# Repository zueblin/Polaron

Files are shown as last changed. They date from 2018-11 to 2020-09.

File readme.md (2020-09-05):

# Polaron

Polaron is a DIY digital drum machine based on the [Teensy 3.6](https://www.pjrc.com/teensy/) USB Microcontroller plattform.

Main features:

- 16 step sequencer
- 6 instrument tracks
- 16 patterns per track
- load/save projects to SD card
- 2 pots for parameter control
- parameter locks: all instrument parameters can be recorded for each step
- different pattern length for each instrument track
- sync to midi-clock (usb-midi) or trigger input
- crunchy 12bit stereo outputs
- open source hardware/software: if you miss a feature or are annoyed by a bug... change it!

Disclaimer: This is a DIY project, features may change or not work for you. Use at your own risk.

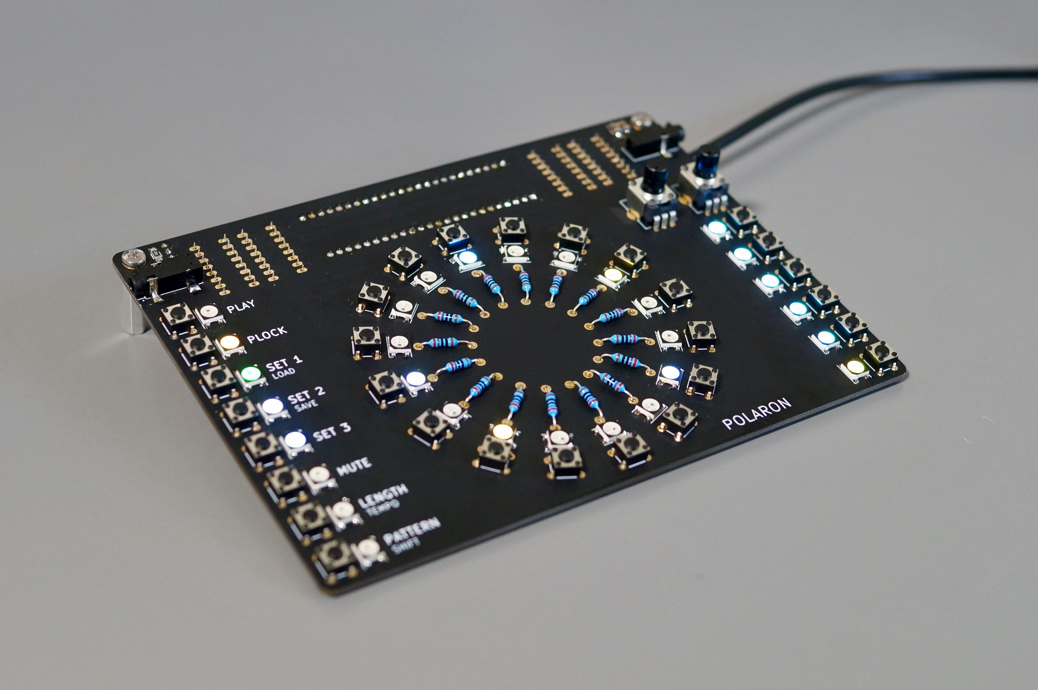
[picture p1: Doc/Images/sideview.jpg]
Sideview


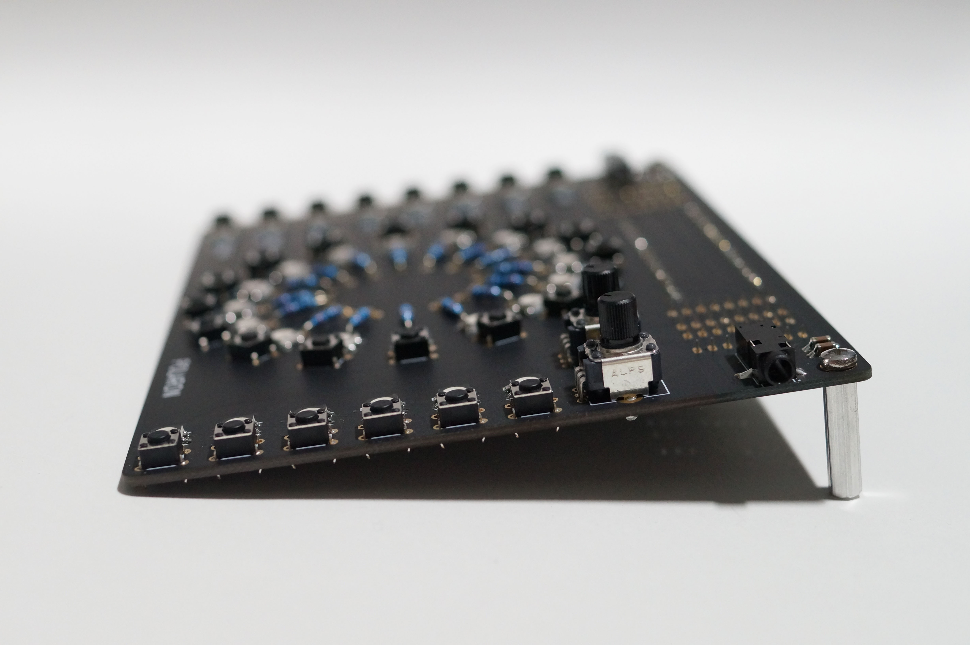
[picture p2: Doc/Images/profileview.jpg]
Profile


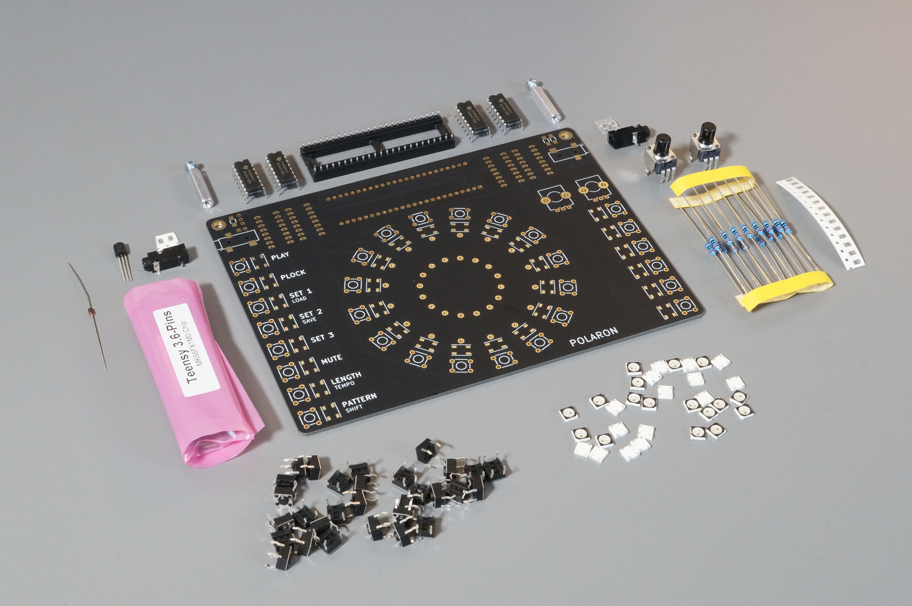
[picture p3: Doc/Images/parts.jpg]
Parts


here's some short videos:

https://www.youtube.com/watch?v=JC_pZTxMb0c

https://vimeo.com/302283771

https://vimeo.com/305113707

Follow the project on Instagram: https://www.instagram.com/polaron.me/

And don't forget to check the [Project WIKI](https://github.com/zueblin/Polaron/wiki) for more info.

## Software

To build the software, the following tools are required:

- [Arduino IDE](https://www.arduino.cc/en/Main/Software) (tested with 1.8.6)
- [Teensyduino Add-On](https://www.pjrc.com/teensy/teensyduino.html) (tested with 1.43)

## Hardware

PCB is designed using KICAD 5.1.2

Parts needed (Rev 1.4):

- Teensy 3.6 32bit Microcontroller (with Headers)
- 30 x WS2812b RGB LEDs (or SK6812)
- 30 x 6x6mm Pushbuttons (ideally 4.3mm height, 100gf) (Mouser: 688-SKHHAJ)
- 16 x 270 ohm throughhole Resistors (Mouser: 603-MF0207FTE52-270R)
- 14 x 270 ohm SMD Resistors (1206 housing)
- 2 x 10k SMD Resistors (1206 housing)
- 1 x 1N4148 diode
- 1 x 2N3904BU transistor
- 4 x SN74HC165N Shiftregister (Mouser: 595-SN74HC165N)
- 2 x ALPS Potentiometer (RK09K1130A8G)
- 2 x 2.2 uF SMD Capacitor (1206 housing, Mouser: 963-TMK316BJ225KL-T)
- 2 x Audio Jack (SJ-352X-SMT)
- 1 x 48 Position / 2 Row IC DIP Socket (Mouser: 517-4848-6004-CP)
- 2 x 20mm PCB Standoff with 3mm thread (Mouser: 534-24437)

Check the Wiki for [Build Instructions](https://github.com/zueblin/Polaron/wiki/Building-the-Polaron)

## Known Issues:
PCB Rev 1.4

- In some situations, when connecting the polaron to a computer via usb and connecting the polaron audio output to an audio interface that is connected to the computer (e.g via thunderbolt), a ground loop is created. This results in a very noticable noise/whine in the audio channel (which is caused by the LED PWM). Tested solution: [Audio Ground Loop Noise Isolator](https://www.pjrc.com/store/audio_ground_isolator.html)

## FAQ

- Q: Is this an easy build? A: This is an intermediate project to build. Its not very complicated, but there are some SMD parts which are not easy to get right (the LEDs). You'll need a decent soldering iron, with a rather fine tip.
- Q: Is this a pro audio project? A: No, not exactly. The Polaron is more about a fun workflow than super hifi sound.
- Q: Does it work with a Teensy 3.5? A: PJRC forum member drjohn reports successfully running the Polaron with a Teensy 3.5.
- Q: Does it work with a Teensy 4.0 / 4.1? A: No, the Polaron relies on the internal DAC of the Teensy 3.6 and is not compatible with Teensy 4.0 / 4.1
- Q: Is there a manual? A: Yes, please check the [Project WIKI](https://github.com/zueblin/Polaron/wiki) for build instructions and operating manual. If you still have questions / suggestions, please send me a mail.
- Q: Does the polaron fit into a euro-rack? A: No, not really (PCB size is 15.7cm x 11.6cm). Polaron builder N.Shaver has experimented with a 3D printable eurorack case for the polaron which he shares on [Thingiverse](https://www.thingiverse.com/thing:3830556)
- Q: Can i buy a PCB? A: Sold out, but let me know if you'd be interested in buying one. ~~Yes, i currently have PCBs at 15 USD (+ shipping from switzerland). Please contact me by email, if interested.~~
- Q: Can i buy a part-kit? A: I don't sell part kits anymore, since it is very easy and efficient to order parts online, eg. from mouser. ~~Yes, i currently have part kits (PCB + all parts, EXCLUDING the teensy itself) at 60 USD incl. untracked international shipping. Add 5 USD for tracked shipping. Please send me a mail, if interested.~~
- Q: Can i buy a fully assembled Polaron? A: Not, not at the moment.
- Q: How can i support this project? A: Spread the word, star the project on github, let your friends know, buy a PCB, build a Polaron and share a video...there are many ways. In general, knowing that this project sparks some interest is what keeps it going!

# License

Code: MIT

Hardware: cc-by-sa-3.0

By: Thomas Zueblin (thomas.zueblin@gmail.com)

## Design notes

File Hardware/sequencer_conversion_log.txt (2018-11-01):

#********** START OF renumber-sheet.ulp ULP Version 4.4.4 10-11-2017 :09:17:23 LOG **********#
    Conversion completed with no Messages
#********** END OF renumber-sheet.ulp ULP Version 4.4.4 10-11-2017 :09:17:23 LOG **********#

#********** START OF fix_via_hack.ulp ULP Version 4.8.0 10-11-2017 :09:17:44 LOG **********#
VIA	ViaCount=1		Net=N$9				(X=8890.000000 Y=25400.000000)	LayerStart=1	LayerEnd=16
VIA	ViaCount=2		Net=N$10				(X=21590.000000 Y=30480.000000)	LayerStart=1	LayerEnd=16
VIA	ViaCount=3		Net=N$11				(X=17780.000000 Y=35560.000000)	LayerStart=1	LayerEnd=16
VIA	ViaCount=4		Net=N$12				(X=64770.000000 Y=31750.000000)	LayerStart=1	LayerEnd=16
VIA	ViaCount=5		Net=N$13				(X=39370.000000 Y=31750.000000)	LayerStart=1	LayerEnd=16
VIA	ViaCount=6		Net=N$14				(X=41910.000000 Y=17780.000000)	LayerStart=1	LayerEnd=16
VIA	ViaCount=7		Net=N$15				(X=62230.000000 Y=17780.000000)	LayerStart=1	LayerEnd=16
VIA	ViaCount=8		Net=N$16				(X=21590.000000 Y=17780.000000)	LayerStart=1	LayerEnd=16
VIA	ViaCount=9		Net=N$17				(X=71120.000000 Y=24130.000000)	LayerStart=1	LayerEnd=16
PADFILL	PadCount=19		Net=GND				(X=6680.000000 Y=15912.000000)	LayerStart=1	LayerEnd=1
PADFILL	PadCount=23		Net=GND				(X=16840.000000 Y=15912.000000)	LayerStart=1	LayerEnd=1
PADFILL	PadCount=27		Net=GND				(X=27000.000000 Y=15912.000000)	LayerStart=1	LayerEnd=1
PADFILL	PadCount=31		Net=GND				(X=37160.000000 Y=15912.000000)	LayerStart=1	LayerEnd=1
PADFILL	PadCount=35		Net=GND				(X=47320.000000 Y=15912.000000)	LayerStart=1	LayerEnd=1
PADFILL	PadCount=39		Net=GND				(X=57480.000000 Y=15912.000000)	LayerStart=1	LayerEnd=1
PADFILL	PadCount=43		Net=GND				(X=67640.000000 Y=15912.000000)	LayerStart=1	LayerEnd=1
PADFILL	PadCount=47		Net=GND				(X=77800.000000 Y=15912.000000)	LayerStart=1	LayerEnd=1
#********** END OF fix_via_hack.ulp ULP Version 4.8.0 10-11-2017 :09:17:44 LOG **********#

#********** START OF eagle6xx-sch-to-kicad-sch.ulp 2.0 10-11-2017 :09:18:30 LOG **********#
    Conversion completed with no Messages
#********** END OF eagle6xx-sch-to-kicad-sch.ulp 2.0 10-11-2017 :09:18:30 LOG **********#

#********** START OF exp-lbrs.ulp 6.8 10-11-2017 :09:19:15 LOG **********#
OK: Eagle library export from SCH/PCB successful
    Conversion completed with no messages
#********** END OF exp-lbrs.ulp 6.8 10-11-2017 :09:19:15 LOG **********#

#********** START OF eagle-lbr2kicad-1.0.ulp 3.1 10-11-2017 :09:19:25 LOG **********#
    Conversion completed with no Messages
#********** END OF eagle-lbr2kicad-1.0.ulp 3.1 10-11-2017 :09:19:25 LOG **********#

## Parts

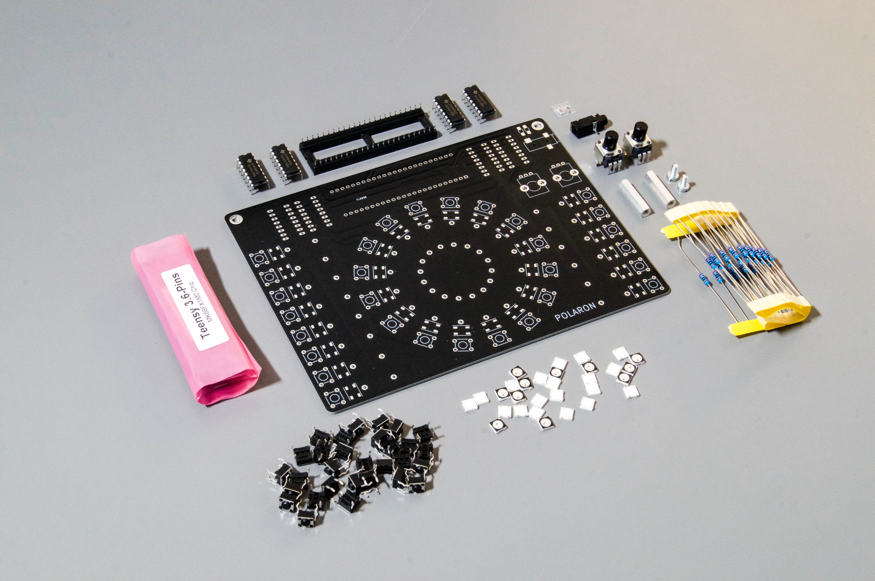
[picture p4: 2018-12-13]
Doc/Images/assembly/parts.jpg

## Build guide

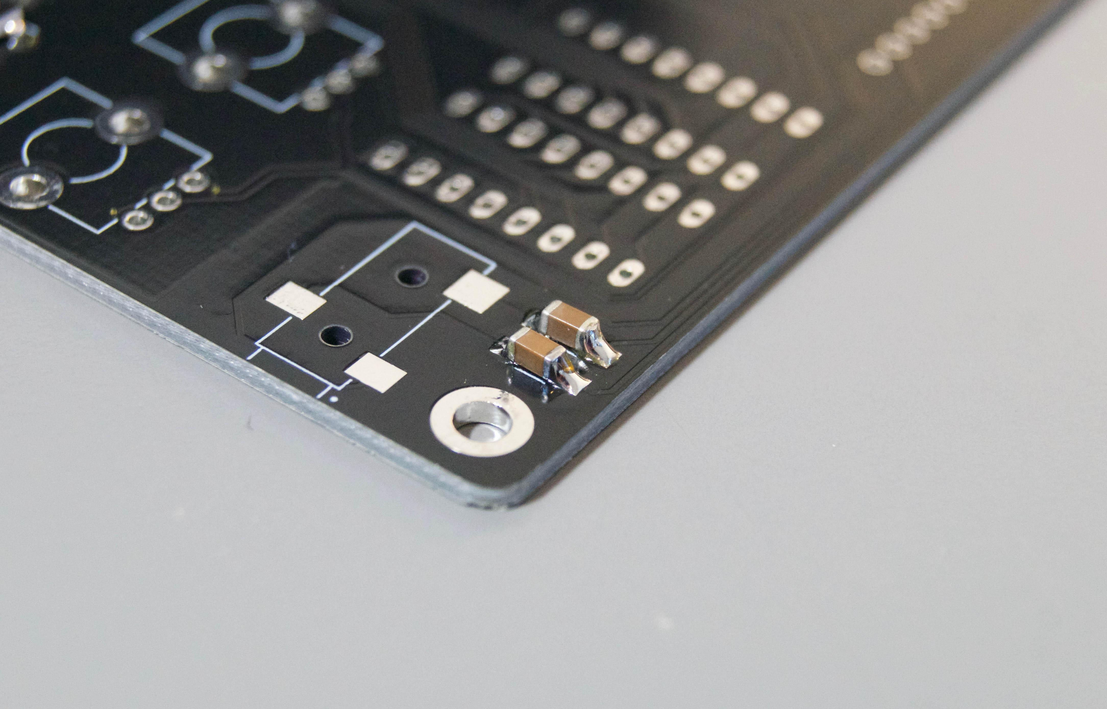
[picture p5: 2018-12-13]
Doc/Images/assembly/smd-cap.jpg

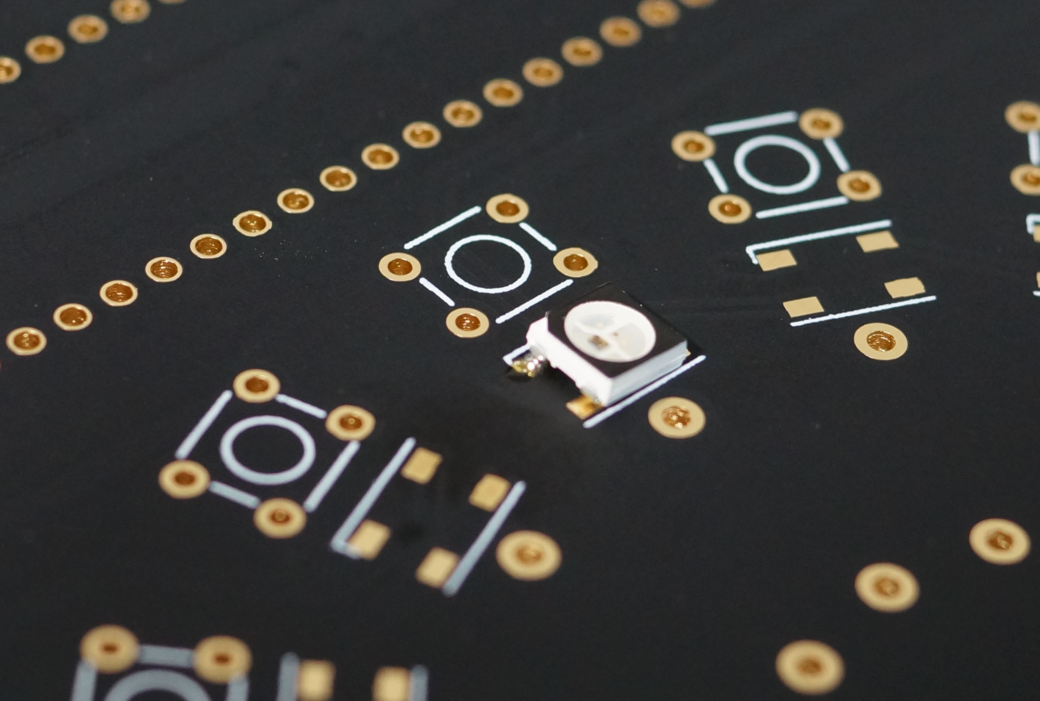
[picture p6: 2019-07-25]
Doc/Images/assembly/rev-1.4/led-dot-1.jpg

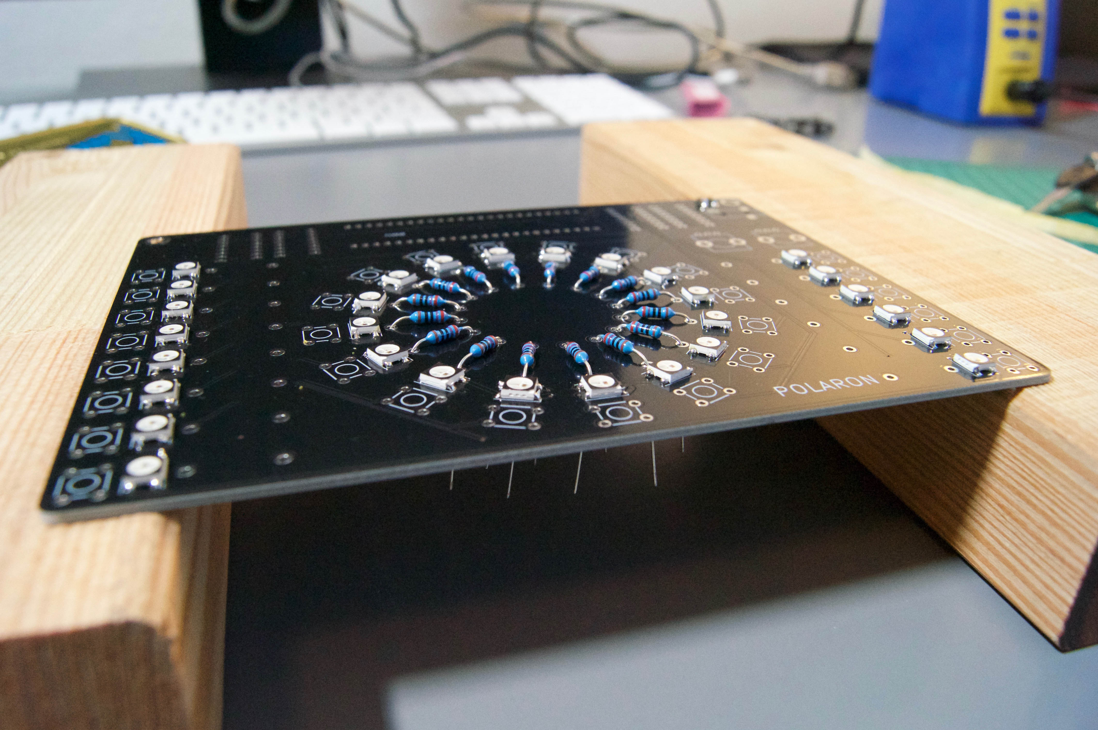
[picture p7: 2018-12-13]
Doc/Images/assembly/resistors.jpg

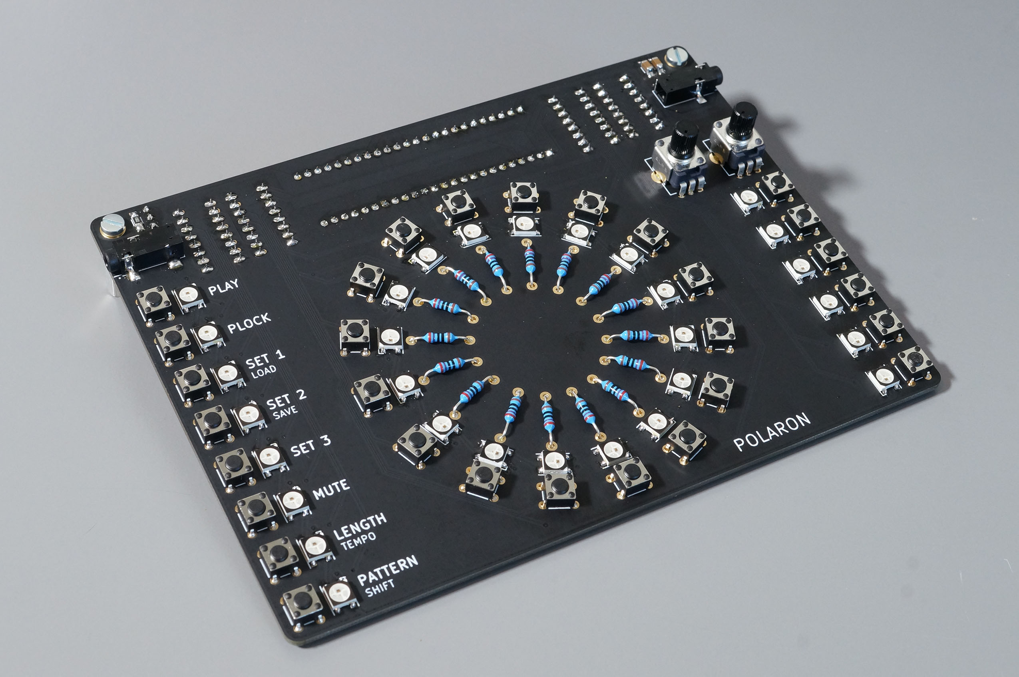
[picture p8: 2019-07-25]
Doc/Images/assembly/rev-1.4/all-done.jpg

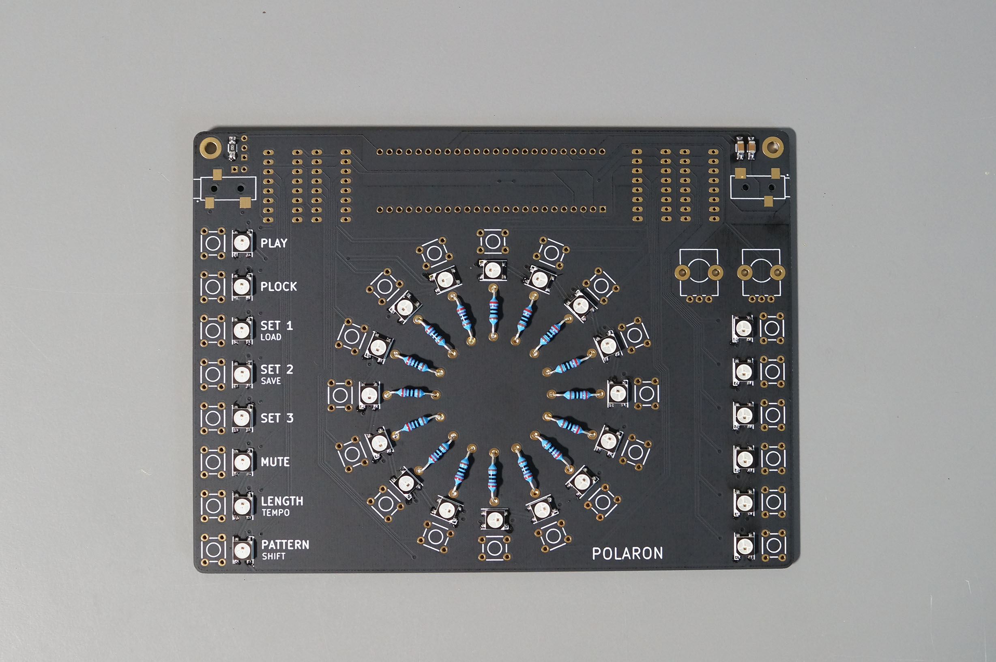
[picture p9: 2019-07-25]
Doc/Images/assembly/rev-1.4/throughhole-resistors-done.jpg

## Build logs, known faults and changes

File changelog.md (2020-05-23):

# Software

## Firmware v1.2.0
* Conditional Triggers: Play a trigger only every n-th time a pattern is looped
* Auto-mutate feature can change active triggers in a track everytime the loop is started again
* Channel 5 (the second 'hihat-like' channel) is replaced by a new Instrument
* Project naming on SD card changed due to length limitation (Old: PROJECT1.TXT, new P_1.TXT).

After updating to this version, you will not be able to load projects stored with v1.1.0. In order to load these projects, manually rename them on the SD card, so that they are in the format P_0.TXT to P_15.TXT. Also due to the change with Channel 5, projects will not sound the same. If you prefer to keep the old Channel 5 simply change the following line in Polaron.ino from

    //BroadbandNoiseChannel channel5;
    BapChannel channel5;
to

    BroadbandNoiseChannel channel5;
    // BapChannel channel5;

## Firmware v1.1.0
* Store/Load projects from Micro SD card

## Firmware v1.0.0
* 16 step sequencer
* 6 instrument tracks
* 16 patterns per track
* 2 pots for parameter control
* parameter locks: all instrument parameters can be recorded for each step
* different pattern length for each instrument track
* internal clock / midi sync / trigger input (PCB rev 1.3 needed for trigger input)
* swing

# Hardware
## PCB rev 1.4
* changed some of the throughhole resistors to smd parts, so that there is space for labeling function buttons on the PCB

## PCB rev 1.3
* Fixed rotation of the potentiometers
* Added a trigger input

## PCB rev 1.2
* Added two drilled holes for standoff

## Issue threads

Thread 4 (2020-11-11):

Comilierungsproblem

Tom04031959, 2020-11-11:
Arduino: 1.8.13 (Windows 10), TD: 1.53, Board: "Teensy 3.6, Serial + MIDI, 180 MHz, Faster, US English"

C:\Program Files (x86)\Arduino\arduino-builder -dump-prefs -logger=machine -hardware C:\Program Files (x86)\Arduino\hardware -hardware C:\Users\TomPC\AppData\Local\Arduino15\packages -tools C:\Program Files (x86)\Arduino\tools-builder -tools C:\Program Files (x86)\Arduino\hardware\tools\avr -tools C:\Users\TomPC\AppData\Local\Arduino15\packages -built-in-libraries C:\Program Files (x86)\Arduino\libraries -libraries C:\Users\TomPC\Documents\Arduino\libraries -fqbn=teensy:avr:teensy36:usb=serialmidi,speed=180,opt=o2std,keys=en-us -ide-version=10813 -build-path C:\Users\TomPC\AppData\Local\Temp\arduino_build_151236 -warnings=none -build-cache C:\Users\TomPC\AppData\Local\Temp\arduino_cache_295598 -verbose C:\Users\TomPC\AppData\Local\Temp\Polaron\Polaron.ino

C:\Program Files (x86)\Arduino\arduino-builder -compile -logger=machine -hardware C:\Program Files (x86)\Arduino\hardware -hardware C:\Users\TomPC\AppData\Local\Arduino15\packages -tools C:\Program Files (x86)\Arduino\tools-builder -tools C:\Program Files (x86)\Arduino\hardware\tools\avr -tools C:\Users\TomPC\AppData\Local\Arduino15\packages -built-in-libraries C:\Program Files (x86)\Arduino\libraries -libraries C:\Users\TomPC\Documents\Arduino\libraries -fqbn=teensy:avr:teensy36:usb=serialmidi,speed=180,opt=o2std,keys=en-us -ide-version=10813 -build-path C:\Users\TomPC\AppData\Local\Temp\arduino_build_151236 -warnings=none -build-cache C:\Users\TomPC\AppData\Local\Temp\arduino_cache_295598 -verbose C:\Users\TomPC\AppData\Local\Temp\Polaron\Polaron.ino

Using board 'teensy36' from platform in folder: C:\Program Files (x86)\Arduino\hardware\teensy\avr

Using core 'teensy3' from platform in folder: C:\Program Files (x86)\Arduino\hardware\teensy\avr

Detecting libraries used...

"C:\\Program Files (x86)\\Arduino\\hardware\\teensy/../tools/arm/bin/arm-none-eabi-g++" -E -CC -x c++ -w -g -Wall -ffunction-sections -fdata-sections -nostdlib -fno-exceptions -fpermissive -felide-constructors -std=gnu++14 -Wno-error=narrowing -fno-rtti -mthumb -mcpu=cortex-m4 -mfloat-abi=hard -mfpu=fpv4-sp-d16 -fsingle-precision-constant -D__MK66FX1M0__ -DTEENSYDUINO=153 -DARDUINO=10813 -DARDUINO_TEENSY36 -DF_CPU=180000000 -DUSB_MIDI_SERIAL -DLAYOUT_US_ENGLISH "-IC:\\Program Files (x86)\\Arduino\\hardware\\teensy\\avr\\cores\\teensy3" "C:\\Users\\TomPC\\AppData\\Local\\Temp\\arduino_build_151236\\sketch\\Polaron.ino.cpp" -o nul -DARDUINO_LIB_DISCOVERY_PHASE

Alternatives for Bounce2.h: [Bounce2@2.21]

ResolveLibrary(Bounce2.h)

  -> candidates: [Bounce2@2.21]

"C:\\Program Files (x86)\\Arduino\\hardware\\teensy/../tools/arm/bin/arm-none-eabi-g++" -E -CC -x c++ -w -g -Wall -ffunction-sections -fdata-sections -nostdlib -fno-exceptions -fpermissive -felide-constructors -std=gnu++14 -Wno-error=narrowing -fno-rtti -mthumb -mcpu=cortex-m4 -mfloat-abi=hard -mfpu=fpv4-sp-d16 -fsingle-precision-constant -D__MK66FX1M0__ -DTEENSYDUINO=153 -DARDUINO=10813 -DARDUINO_TEENSY36 -DF_CPU=180000000 -DUSB_MIDI_SERIAL -DLAYOUT_US_ENGLISH "-IC:\\Program Files (x86)\\Arduino\\hardware\\teensy\\avr\\cores\\teensy3" "-IC:\\Program Files (x86)\\Arduino\\hardware\\teensy\\avr\\libraries\\Bounce2" "C:\\Users\\TomPC\\AppData\\Local\\Temp\\arduino_build_151236\\sketch\\Polaron.ino.cpp" -o nul -DARDUINO_LIB_DISCOVERY_PHASE

Alternatives for FastLED.h: [FastLED@3.3.3 FastLED@3.3.3]

ResolveLibrary(FastLED.h)

  -> candidates: [FastLED@3.3.3 FastLED@3.3.3]

"C:\\Program Files (x86)\\Arduino\\hardware\\teensy/../tools/arm/bin/arm-none-eabi-g++" -E -CC -x c++ -w -g -Wall -ffunction-sections -fdata-sections -nostdlib -fno-exceptions -fpermissive -felide-constructors -std=gnu++14 -Wno-error=narrowing -fno-rtti -mthumb -mcpu=cortex-m4 -mfloat-abi=hard -mfpu=fpv4-sp-d16 -fsingle-precision-constant -D__MK66FX1M0__ -DTEENSYDUINO=153 -DARDUINO=10813 -DARDUINO_TEENSY36 -DF_CPU=180000000 -DUSB_MIDI_SERIAL -DLAYOUT_US_ENGLISH "-IC:\\Program Files (x86)\\Arduino\\hardware\\teensy\\avr\\cores\\teensy3" "-IC:\\Program Files (x86)\\Arduino\\hardware\\teensy\\avr\\libraries\\Bounce2" "-IC:\\Users\\TomPC\\Documents\\Arduino\\libraries\\FastLED" "C:\\Users\\TomPC\\AppData\\Local\\Temp\\arduino_build_151236\\sketch\\Polaron.ino.cpp" -o nul -DARDUINO_LIB_DISCOVERY_PHASE

Alternatives for Audio.h: [Audio@1.3 Audio@1.0.5]

ResolveLibrary(Audio.h)

  -> candidates: [Audio@1.3 Audio@1.0.5]

"C:\\Program Files (x86)\\Arduino\\hardware\\teensy/../tools/arm/bin/arm-none-eabi-g++" -E -CC -x c++ -w -g -Wall -ffunction-sections -fdata-sections -nostdlib -fno-exceptions -fpermissive -felide-constructors -std=gnu++14 -Wno-error=narrowing -fno-rtti -mthumb -mcpu=cortex-m4 -mfloat-abi=hard -mfpu=fpv4-sp-d16 -fsingle-precision-constant -D__MK66FX1M0__ -DTEENSYDUINO=153 -DARDUINO=10813 -DARDUINO_TEENSY36 -DF_CPU=180000000 -DUSB_MIDI_SERIAL -DLAYOUT_US_ENGLISH "-IC:\\Program Files (x86)\\Arduino\\hardware\\teensy\\avr\\cores\\teensy3" "-IC:\\Program Files (x86)\\Arduino\\hardware\\teensy\\avr\\libraries\\Bounce2" "-IC:\\Users\\TomPC\\Documents\\Arduino\\libraries\\FastLED" "-IC:\\Program Files (x86)\\Arduino\\hardware\\teensy\\avr\\libraries\\Audio" "C:\\Users\\TomPC\\AppData\\Local\\Temp\\arduino_build_151236\\sketch\\Polaron.ino.cpp" -o nul -DARDUINO_LIB_DISCOVERY_PHASE

Alternatives for SPI.h: [SPI@1.0]

ResolveLibrary(SPI.h)

  -> candidates: [SPI@1.0]

"C:\\Program Files (x86)\\Arduino\\hardware\\teensy/../tools/arm/bin/arm-none-eabi-g++" -E -CC -x c++ -w -g -Wall -ffunction-sections -fdata-sections -nostdlib -fno-exceptions -fpermissive -felide-constructors -std=gnu++14 -Wno-error=narrowing -fno-rtti -mthumb -mcpu=cortex-m4 -mfloat-abi=hard -mfpu=fpv4-sp-d16 -fsingle-precision-constant -D__MK66FX1M0__ -DTEENSYDUINO=153 -DARDUINO=10813 -DARDUINO_TEENSY36 -DF_CPU=180000000 -DUSB_MIDI_SERIAL -DLAYOUT_US_ENGLISH "-IC:\\Program Files (x86)\\Arduino\\hardware\\teensy\\avr\\cores\\teensy3" "-IC:\\Program Files (x86)\\Arduino\\hardware\\teensy\\avr\\libraries\\Bounce2" "-IC:\\Users\\TomPC\\Documents\\Arduino\\libraries\\FastLED" "-IC:\\Program Files (x86)\\Arduino\\hardware\\teensy\\avr\\libraries\\Audio" "-IC:\\Program Files (x86)\\Arduino\\hardware\\teensy\\avr\\libraries\\SPI" "C:\\Users\\TomPC\\AppData\\Local\\Temp\\arduino_build_151236\\sketch\\Polaron.ino.cpp" -o nul -DARDUINO_LIB_DISCOVERY_PHASE

Alternatives for SD.h: [SD@1.2.4 SD@1.2.2 SD@1.2.4]

ResolveLibrary(SD.h)

  -> candidates: [SD@1.2.4 SD@1.2.2 SD@1.2.4]

"C:\\Program Files (x86)\\Arduino\\hardware\\teensy/../tools/arm/bin/arm-none-eabi-g++" -E -CC -x c++ -w -g -Wall -ffunction-sections -fdata-sections -nostdlib -fno-exceptions -fpermissive -felide-constructors -std=gnu++14 -Wno-error=narrowing -fno-rtti -mthumb -mcpu=cortex-m4 -mfloat-abi=hard -mfpu=fpv4-sp-d16 -fsingle-precision-constant -D__MK66FX1M0__ -DTEENSYDUINO=153 -DARDUINO=10813 -DARDUINO_TEENSY36 -DF_CPU=180000000 -DUSB_MIDI_SERIAL -DLAYOUT_US_ENGLISH "-IC:\\Program Files (x86)\\Arduino\\hardware\\teensy\\avr\\cores\\teensy3" "-IC:\\Program Files (x86)\\Arduino\\hardware\\teensy\\avr\\libraries\\Bounce2" "-IC:\\Users\\TomPC\\Documents\\Arduino\\libraries\\FastLED" "-IC:\\Program Files (x86)\\Arduino\\hardware\\teensy\\avr\\libraries\\Audio" "-IC:\\Program Files (x86)\\Arduino\\hardware\\teensy\\avr\\libraries\\SPI" "-IC:\\Users\\TomPC\\Documents\\Arduino\\libraries\\SD\\src" "C:\\Users\\TomPC\\AppData\\Local\\Temp\\arduino_build_151236\\sketch\\Polaron.ino.cpp" -o nul -DARDUINO_LIB_DISCOVERY_PHASE

Alternatives for SerialFlash.h: [SerialFlash@0.5]

ResolveLibrary(SerialFlash.h)

  -> candidates: [SerialFlash@0.5]

"C:\\Program Files (x86)\\Arduino\\hardware\\teensy/../tools/arm/bin/arm-none-eabi-g++" -E -CC -x c++ -w -g -Wall -ffunction-sections -fdata-sections -nostdlib -fno-exceptions -fpermissive -felide-constructors -std=gnu++14 -Wno-error=narrowing -fno-rtti -mthumb -mcpu=cortex-m4 -mfloat-abi=hard -mfpu=fpv4-sp-d16 -fsingle-precision-constant -D__MK66FX1M0__ -DTEENSYDUINO=153 -DARDUINO=10813 -DARDUINO_TEENSY36 -DF_CPU=180000000 -DUSB_MIDI_SERIAL -DLAYOUT_US_ENGLISH "-IC:\\Program Files (x86)\\Arduino\\hardware\\teensy\\avr\\cores\\teensy3" "-IC:\\Program Files (x86)\\Arduino\\hardware\\teensy\\avr\\libraries\\Bounce2" "-IC:\\Users\\TomPC\\Documents\\Arduino\\libraries\\FastLED" "-IC:\\Program Files (x86)\\Arduino\\hardware\\teensy\\avr\\libraries\\Audio" "-IC:\\Program Files (x86)\\Arduino\\hardware\\teensy\\avr\\libraries\\SPI" "-IC:\\Users\\TomPC\\Documents\\Arduino\\libraries\\SD\\src" "-IC:\\Program Files (x86)\\Arduino\\hardware\\teensy\\avr\\libraries\\SerialFlash" "C:\\Users\\TomPC\\AppData\\Local\\Temp\\arduino_build_151236\\sketch\\Polaron.ino.cpp" -o nul -DARDUINO_LIB_DISCOVERY_PHASE

Alternatives for USBHost_t36.h: [USBHost_t36@0.1]

ResolveLibrary(USBHost_t36.h)

  -> candidates: [USBHost_t36@0.1]

"C:\\Program Files (x86)\\Arduino\\hardware\\teensy/../tools/arm/bin/arm-none-eabi-g++" -E -CC -x c++ -w -g -Wall -ffunction-sections -fdata-sections -nostdlib -fno-exceptions -fpermissive -felide-constructors -std=gnu++14 -Wno-error=narrowing -fno-rtti -mthumb -mcpu=cortex-m4 -mfloat-abi=hard -mfpu=fpv4-sp-d16 -fsingle-precision-constant -D__MK66FX1M0__ -DTEENSYDUINO=153 -DARDUINO=10813 -DARDUINO_TEENSY36 -DF_CPU=180000000 -DUSB_MIDI_SERIAL -DLAYOUT_US_ENGLISH "-IC:\\Program Files (x86)\\Arduino\\hardware\\teensy\\avr\\cores\\teensy3" "-IC:\\Program Files (x86)\\Arduino\\hardware\\teensy\\avr\\libraries\\Bounce2" "-IC:\\Users\\TomPC\\Documents\\Arduino\\libraries\\FastLED" "-IC:\\Program Files (x86)\\Arduino\\hardware\\teensy\\avr\\libraries\\Audio" "-IC:\\Program Files (x86)\\Arduino\\hardware\\teensy\\avr\\libraries\\SPI" "-IC:\\Users\\TomPC\\Documents\\Arduino\\libraries\\SD\\src" "-IC:\\Program Files (x86)\\Arduino\\hardware\\teensy\\avr\\libraries\\SerialFlash" "-IC:\\Program Files (x86)\\Arduino\\hardware\\teensy\\avr\\libraries\\USBHost_t36" "C:\\Users\\TomPC\\AppData\\Local\\Temp\\arduino_build_151236\\sketch\\Polaron.ino.cpp" -o nul -DARDUINO_LIB_DISCOVERY_PHASE

"C:\\Program Files (x86)\\Arduino\\hardware\\teensy/../tools/arm/bin/arm-none-eabi-g++" -E -CC -x c++ -w -g -Wall -ffunction-sections -fdata-sections -nostdlib -fno-exceptions -fpermissive -felide-constructors -std=gnu++14 -Wno-error=narrowing -fno-rtti -mthumb -mcpu=cortex-m4 -mfloat-abi=hard -mfpu=fpv4-sp-d16 -fsingle-precision-constant -D__MK66FX1M0__ -DTEENSYDUINO=153 -DARDUINO=10813 -DARDUINO_TEENSY36 -DF_CPU=180000000 -DUSB_MIDI_SERIAL -DLAYOUT_US_ENGLISH "-IC:\\Program Files (x86)\\Arduino\\hardware\\teensy\\avr\\cores\\teensy3" "-IC:\\Program Files (x86)\\Arduino\\hardware\\teensy\\avr\\libraries\\Bounce2" "-IC:\\Users\\TomPC\\Documents\\Arduino\\libraries\\FastLED" "-IC:\\Program Files (x86)\\Arduino\\hardware\\teensy\\avr\\libraries\\Audio" "-IC:\\Program Files (x86)\\Arduino\\hardware\\teensy\\avr\\libraries\\SPI" "-IC:\\Users\\TomPC\\Documents\\Arduino\\libraries\\SD\\src" "-IC:\\Program Files (x86)\\Arduino\\hardware\\teensy\\avr\\libraries\\SerialFlash" "-IC:\\Program Files (x86)\\Arduino\\hardware\\teensy\\avr\\libraries\\USBHost_t36" "C:\\Users\\TomPC\\AppData\\Local\\Temp\\arduino_build_151236\\sketch\\AudioPlayPitchedMemory.cpp" -o nul -DARDUINO_LIB_DISCOVERY_PHASE
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

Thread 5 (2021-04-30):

Vague code question - I would like to add a lowpass filter to the final mix

ivogrig, 2021-04-30:
First of all, I love this sequencer. Only I find the tones sometimes a bit too harsh, so I would like to insert a lowpass-filter with a fixed frequency (to keep it simple) into the final mixing stage.
I skimmed through the code a bit but was not quite sure so I thought I ask. I hope I am not annoying you.
It looks like the effects and filters are classes from the teensy library, so I guess I could just add one at the bottom for each track, but really only need one.
I don't know anything about teensy but I might just need to get through the documentation.
Any help is appreciated anyways.

zueblin, 2021-04-30:
I think you could try to just add two filter objects (see teensy audio design tool for details) after mixer1 and mixer2 and before the DAC object (two, because you'll want stereo filtering)
See https://github.com/zueblin/Polaron/blob/master/Software/Polaron/Polaron.ino#L72-L74
You'll also need to reconfigure the AudioConnections (you'll need two new connections) so that the signal doesn't go from mixer1/2 to dac, but from mixer1/" to filter1/2 and then from filter1/2 to dac.
see https://github.com/zueblin/Polaron/blob/master/Software/Polaron/Polaron.ino#L89-L90

If your unsure about the Code, just use the teensy audio design tool to create the connections and let it output the code for you. Then copy/paste (plus slightly adapt) it and add to Polaron.ino.

Hope this helps

ivogrig, 2021-05-01:
Thanks for the quick reply, yes I think that helps!
I will close the issue

Closed 2021-05-01.

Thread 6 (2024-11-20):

POT A doesn't work

stilltryin, 2024-11-20:
Hi, i just build a polaron and my right pot (pot 2) isn't working ...double checked all traces and connections and it seems to be software (maybe an updated library or sth.)? Everything else works like a charm...Can u send me a compiled version of the software to try?

Closed 2024-11-24.

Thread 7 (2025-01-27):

Schematic Available?

lonesoulsurfer, 2025-01-27:
Howdy,

Sorry this isn't really an issue but I was hoping that you might have a schemafic available in PDF?  I've tried to open the Eagle file but I get an error coming up.  I'm looking to have a play around with the design and see if I can fit it into a eurorack config.

Great build by the way - thanks for sharing.

Marcus

wimjanse, 2025-01-27:
See attached file

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

zueblin, 2025-01-31:
Thanks @wimjanse for helping here, i'll close the issue.

lonesoulsurfer, 2025-02-02:
Thanks so much for sending through the schematic.

All the best
Marcus

On 31 Jan 2025, at 6:57 pm, zueblin ***@***.***> wrote:

Thanks @wimjanse<https://github.com/wimjanse> for helping here, i'll close the issue.

—
Reply to this email directly, view it on GitHub<https://github.com/zueblin/Polaron/issues/7#issuecomment-2626520243>, or unsubscribe<https://github.com/notifications/unsubscribe-auth/AOO73WGH5OCKMQQVTDXQQAT2NMUFXAVCNFSM6AAAAABV5FFLX2VHI2DSMVQWIX3LMV43OSLTON2WKQ3PNVWWK3TUHMZDMMRWGUZDAMRUGM>.
You are receiving this because you authored the thread.Message ID: ***@***.***>

Closed 2025-01-31.

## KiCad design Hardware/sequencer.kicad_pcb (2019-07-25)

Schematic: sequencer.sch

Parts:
C1, C2: 2.2uF; C_1206_HandSoldering
D1, D2, D3, D4, D5, D6, D7, D8, D9, D10, D11, D12, D13, D14, D15, D16, D17, D18, D19, D20, D21, D22, D23, D24, D25, D26, D27, D28, D29, D30: LED_WS2812B-PLCC4
D31: 1N4148; D_DO-35_SOD27_P2.54mm_Vertical_AnodeUp
IC1, IC2, IC3, IC4: 74HC165N; DIL16
J1, J2: SJ-3523-SMT-TR; CUI_SJ-3523-SMT-TR
Q1: 2N3904; TO-92_Inline_Wide
R1, R2, R3, R4, R5, R6, R7, R8, R9, R10, R11, R12, R13, R14, R15, R16: 270; R_Axial_DIN0411_L9.9mm_D3.6mm_P12.70mm_Horizontal_noSilkscr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
R17, R18, R19, R20, R21, R22, R23, R24, R25, R26, R27, R28, R29, R30: 270; R_1206_HandSoldering
R31, R32: 10k; R_1206_HandSoldering
RV1, RV2: POT; Potentiometer_Alps_RK09K_Horizontal
S1, S2, S3, S4, S5, S6, S7, S8, S9, S10, S11, S12, S13, S14, S15, S16, S17, S18, S19, S20, S21, S22, S23, S24, S25, S26, S27, S28, S29, S30: SWITCH-MOMENTARY-2PTH; TACTILE-PTH
U1: Teensy3.6; Teensy35_36_simple

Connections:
/Audio1: C1.2, J1.3
/Audio2: C2.2, J1.2
/AudioGND: J1.1, U1.52 (AGND)
/JOY_A: RV1.2, U1.50 (23_A9_PWM_Touch)
/JOY_B: RV2.2, U1.49 (22_A8_PWM_Touch)
/LED_IN: D1.4 (DIN), U1.8 (6_PWM)
/LedConn1: D8.2 (DOUT), D9.4 (DIN)
/LedConn2: D16.2 (DOUT), D17.4 (DIN)
/LedConn3: D24.2 (DOUT), D25.4 (DIN)
/SHIFT_CLOCK: IC1.2 (CLK), IC2.2 (CLK), IC3.2 (CLK), IC4.2 (CLK), U1.4 (2_PWM)
/SHIFT_DATA_OUT: IC4.9 (QH), U1.3 (1_TX1_MISO1_Touch)
/SHIFT_PLOAD: IC1.1 (SH/~LD), IC2.1 (SH/~LD), IC3.1 (SH/~LD), IC4.1 (SH/~LD), U1.2 (0_RX1_MOSI1_Touch)
/Trigger-Input: Q1.3 (C), R32.1, U1.30 (33_A14_CAN1TX_scl0)
GND: D1.3 (VSS), D2.3 (VSS), D3.3 (VSS), D4.3 (VSS), D5.3 (VSS), D6.3 (VSS), D7.3 (VSS), D8.3 (VSS), D9.3 (VSS), D10.3 (VSS), D11.3 (VSS), D12.3 (VSS), D13.3 (VSS), D14.3 (VSS), D15.3 (VSS), D16.3 (VSS), D17.3 (VSS), D18.3 (VSS), D19.3 (VSS), D20.3 (VSS), D21.3 (VSS), D22.3 (VSS), D23.3 (VSS), D24.3 (VSS), D25.3 (VSS), D26.3 (VSS), D27.3 (VSS), D28.3 (VSS), D29.3 (VSS), D30.3 (VSS), D31.2 (A), IC1.8 (GND), IC1.15 (INH), IC2.8 (GND), IC2.15 (INH), IC3.8 (GND), IC3.15 (INH), IC4.5 (G), IC4.6 (H), IC4.8 (GND), IC4.15 (INH), J2.1, Q1.1 (E), R1.2, R2.2, R3.2, R4.2, R5.2, R6.2, R7.2, R8.2, R9.2, R10.2, R11.2, R12.2, R13.2, R14.2, R15.2, R16.2, R17.1, R18.1, R19.1, R20.1, R21.1, R22.1, R23.1, R24.1, R25.1, R26.1, R27.1, R28.1, R29.1, R30.1, RV1.3, RV2.3, U1.1 (GND)
unnamed: C1.1, U1.37 (A21_DAC0)
unnamed: C2.1, U1.38 (A22_DAC1)
unnamed: D1.2 (DOUT), D2.4 (DIN)
unnamed: D2.2 (DOUT), D3.4 (DIN)
unnamed: D3.2 (DOUT), D4.4 (DIN)
unnamed: D4.2 (DOUT), D5.4 (DIN)
unnamed: D5.2 (DOUT), D6.4 (DIN)
unnamed: D6.2 (DOUT), D7.4 (DIN)
unnamed: D7.2 (DOUT), D8.4 (DIN)
unnamed: D10.2 (DOUT), D11.4 (DIN)
unnamed: D9.2 (DOUT), D10.4 (DIN)
unnamed: D11.2 (DOUT), D12.4 (DIN)
unnamed: D12.2 (DOUT), D13.4 (DIN)
unnamed: D13.2 (DOUT), D14.4 (DIN)
unnamed: D14.2 (DOUT), D15.4 (DIN)
unnamed: D15.2 (DOUT), D16.4 (DIN)
unnamed: D17.2 (DOUT), D18.4 (DIN)
unnamed: D18.2 (DOUT), D19.4 (DIN)
unnamed: D19.2 (DOUT), D20.4 (DIN)
unnamed: D20.2 (DOUT), D21.4 (DIN)
unnamed: D21.2 (DOUT), D22.4 (DIN)
unnamed: D22.2 (DOUT), D23.4 (DIN)
unnamed: D23.2 (DOUT), D24.4 (DIN)
unnamed: D25.2 (DOUT), D26.4 (DIN)
unnamed: D26.2 (DOUT), D27.4 (DIN)
unnamed: D27.2 (DOUT), D28.4 (DIN)
unnamed: D28.2 (DOUT), D29.4 (DIN)
unnamed: D29.2 (DOUT), D30.4 (DIN)
unnamed: D31.1 (K), Q1.2 (B), R31.2
unnamed: IC1.3 (E), R21.2, S21.3 (2)
unnamed: IC1.4 (F), R22.2, S22.3 (2)
unnamed: IC1.5 (G), R23.2, S23.3 (2)
unnamed: IC1.6 (H), R24.2, S24.3 (2)
unnamed: IC1.9 (QH), IC2.10 (SER)
unnamed: IC1.11 (A), R17.2, S17.3 (2)
unnamed: IC1.12 (B), R18.2, S18.3 (2)
unnamed: IC1.13 (C), R19.2, S19.3 (2)
unnamed: IC1.14 (D), R20.2, S20.3 (2)
unnamed: IC2.3 (E), R13.1, S13.3 (2)
unnamed: IC2.4 (F), R14.1, S14.3 (2)
unnamed: IC2.5 (G), R15.1, S15.3 (2)
unnamed: IC2.6 (H), R16.1, S16.3 (2)
unnamed: IC2.9 (QH), IC3.10 (SER)
unnamed: IC2.11 (A), R9.1, S9.3 (2)
unnamed: IC2.12 (B), R10.1, S10.3 (2)
unnamed: IC2.13 (C), R11.1, S11.3 (2)
unnamed: IC2.14 (D), R12.1, S12.3 (2)
unnamed: IC3.3 (E), R5.1, S5.3 (2)
unnamed: IC3.4 (F), R6.1, S6.3 (2)
unnamed: IC3.5 (G), R7.1, S7.3 (2)
unnamed: IC3.6 (H), R8.1, S8.3 (2)
unnamed: IC3.9 (QH), IC4.10 (SER)
unnamed: IC3.11 (A), R1.1, S1.3 (2)
unnamed: IC3.12 (B), R2.1, S2.3 (2)
unnamed: IC3.13 (C), R3.1, S3.3 (2)
unnamed: IC3.14 (D), R4.1, S4.3 (2)
unnamed: IC4.3 (E), R29.2, S29.3 (2)
unnamed: IC4.4 (F), R30.2, S30.3 (2)
unnamed: IC4.11 (A), R25.2, S25.3 (2)
unnamed: IC4.12 (B), R26.2, S26.3 (2)
unnamed: IC4.13 (C), R27.2, S27.3 (2)
unnamed: IC4.14 (D), R28.2, S28.3 (2)
unnamed: J2.2, R31.1
VCC: D1.1 (VDD), D2.1 (VDD), D3.1 (VDD), D4.1 (VDD), D5.1 (VDD), D6.1 (VDD), D7.1 (VDD), D8.1 (VDD), D9.1 (VDD), D10.1 (VDD), D11.1 (VDD), D12.1 (VDD), D13.1 (VDD), D14.1 (VDD), D15.1 (VDD), D16.1 (VDD), D17.1 (VDD), D18.1 (VDD), D19.1 (VDD), D20.1 (VDD), D21.1 (VDD), D22.1 (VDD), D23.1 (VDD), D24.1 (VDD), D25.1 (VDD), D26.1 (VDD), D27.1 (VDD), D28.1 (VDD), D29.1 (VDD), D30.1 (VDD), IC1.16 (VCC), IC2.16 (VCC), IC3.16 (VCC), IC4.16 (VCC), R32.2, RV1.1, RV2.1, S1.1, S2.1, S3.1, S4.1, S5.1, S6.1, S7.1, S8.1, S9.1, S10.1, S11.1, S12.1, S13.1, S14.1, S15.1, S16.1, S17.1, S18.1, S19.1, S20.1, S21.1, S22.1, S23.1, S24.1, S25.1, S26.1, S27.1, S28.1, S29.1, S30.1, U1.15 (3.3V)

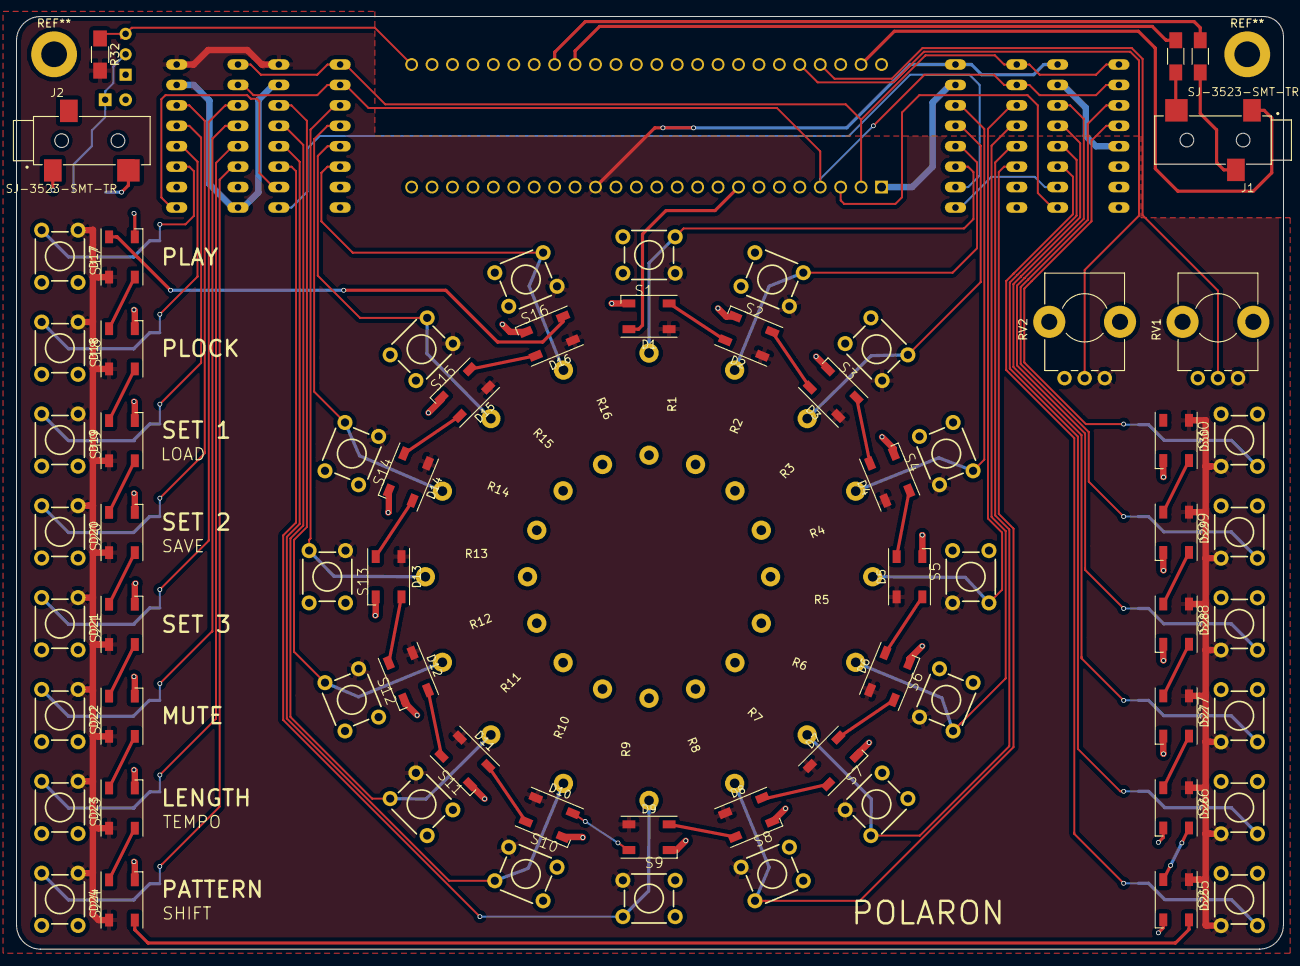
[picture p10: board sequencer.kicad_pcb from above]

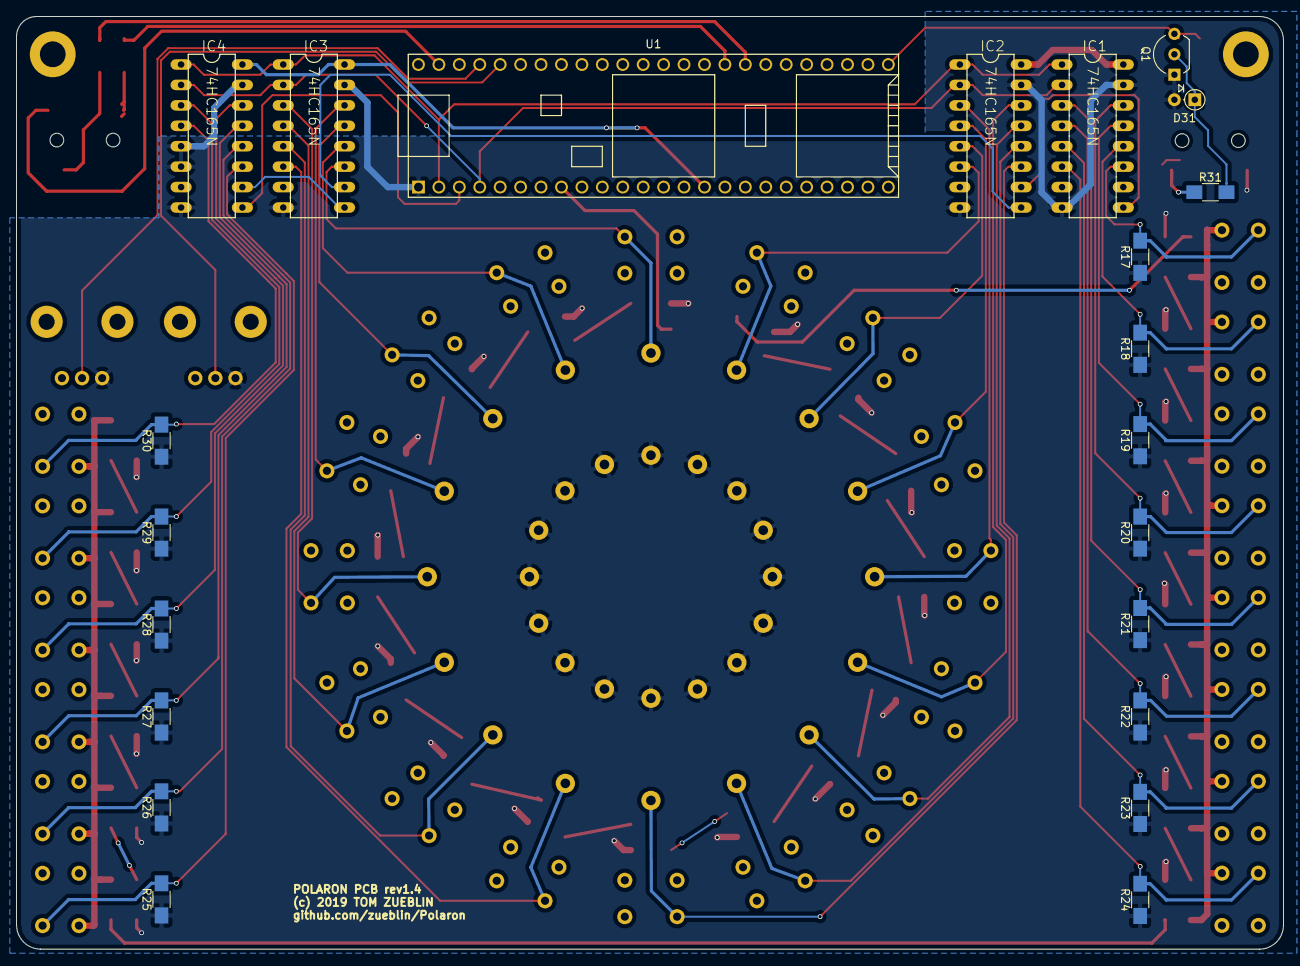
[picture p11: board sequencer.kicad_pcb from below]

Board: 2 copper layers, 157.5 x 116.0 mm, 105 parts (22 on the bottom side), 78 nets.

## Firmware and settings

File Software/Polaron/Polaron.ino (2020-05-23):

// Copyright (c) 2018 Thomas Zueblin
//
// Author: Thomas Zueblin (thomas.zueblin@gmail.com)
//
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
#include <avr/io.h>
#include <avr/interrupt.h>

#include "Bounce2.h"
#include "FastLED.h"
#include "Sequencer.h"
#include "mixer.h"
#include <Audio.h>

#include "ParameterSet.h"
#include "BoomChannel.h"
#include "BroadbandNoiseChannel.h"
#include "BapChannel.h"
#include "DualSineChannel.h"
#include "FMChannel.h"
#include "HatsChannel.h"
#include "SimpleDrumChannel.h"
#include "SimpleSineChannel.h"
//#include "SimpleSampleChannel.h"

#include "USBHost_t36.h"

// allows teensy to become a usb host and receive midi from connected slave devices (normally teensy is a usb slave)
// in order to use this feature you need a special cable: https://www.pjrc.com/store/cable_usb_host_t36.html
// #define ENABLE_USBHOST

#define PULSE_WIDTH_USEC 5

#define SHIFT_IN_PLOAD_PIN 0  // 2  // Connects to Parallel load pin the 165
#define SHIFT_IN_DATA_PIN 1   // 4 // Connects to the Q7 pin the 165
#define SHIFT_IN_CLOCK_PIN 2  // 5 // Connects to the Clock pin the 165
// pin used to send the serial data to the array of leds (via fastLED)
#define DATA_PIN 6

#ifdef ENABLE_USBHOST
USBHost usbHost;
MIDIDevice usbHostMIDI(usbHost);
#endif

BoomChannel channel1;
//SimpleSampleChannel channel2;
SimpleDrumChannel channel2(200, 6000);
// SimpleSineChannel channel3(100, 2000);
FMChannel channel3(0, 1024);
DualSineChannel channel4(16, 2000);
//BroadbandNoiseChannel channel5;
BapChannel channel5;
HatsChannel channel6;

AudioMixer8 mixer1;
AudioMixer8 mixer2;
AudioOutputAnalogStereo dacs1;

AudioConnection patchCord8(*channel1.getOutput1(), 0, mixer1, 0);
AudioConnection patchCord9(*channel2.getOutput1(), 0, mixer1, 1);
AudioConnection patchCord10(*channel3.getOutput1(), 0, mixer1, 2);
AudioConnection patchCord11(*channel4.getOutput1(), 0, mixer1, 3);
AudioConnection patchCord12(*channel5.getOutput1(), 0, mixer1, 4);
AudioConnection patchCord13(*channel6.getOutput1(), 0, mixer1, 5);
AudioConnection patchCord14(*channel1.getOutput2(), 0, mixer2, 0);
AudioConnection patchCord15(*channel2.getOutput2(), 0, mixer2, 1);
AudioConnection patchCord16(*channel3.getOutput2(), 0, mixer2, 2);
AudioConnection patchCord17(*channel4.getOutput2(), 0, mixer2, 3);
AudioConnection patchCord18(*channel5.getOutput2(), 0, mixer2, 4);
AudioConnection patchCord19(*channel6.getOutput2(), 0, mixer2, 5);

AudioConnection patchCord20(mixer1, 0, dacs1, 0);
AudioConnection patchCord21(mixer2, 0, dacs1, 1);

Sequencer sequencer;

bool triggerInputFell = false;

void setup() {
    pinMode(SHIFT_IN_PLOAD_PIN, OUTPUT);
    pinMode(SHIFT_IN_CLOCK_PIN, OUTPUT);
    pinMode(SHIFT_IN_DATA_PIN, INPUT);

    pinMode(TRIGGER_IN_PIN, INPUT_PULLUP);
    attachInterrupt(digitalPinToInterrupt(TRIGGER_IN_PIN), onTriggerInputFell, FALLING); // interrrupt 1 is data ready


    // init input shift register
    digitalWrite(SHIFT_IN_CLOCK_PIN, LOW);
    digitalWrite(SHIFT_IN_PLOAD_PIN, HIGH);

    #ifdef ENABLE_USBHOST
    usbHost.begin();
    usbHostMIDI.setHandleRealTimeSystem(onRealTimeSystem);
    #endif

    usbMIDI.setHandleRealTimeSystem(onRealTimeSystem);


    AudioMemory(70);
    // dacs1.analogReference(EXTERNAL);

    sequencer.audioChannels[0] = &channel1;
    sequencer.audioChannels[1] = &channel2;
    sequencer.audioChannels[2] = &channel3;
    sequencer.audioChannels[3] = &channel4;
    sequencer.audioChannels[4] = &channel5;
    sequencer.audioChannels[5] = &channel6;


    for (int i = 0; i < 6; i++){
        sequencer.tracks[i].init(sequencer.audioChannels[i]->getDefaultParams());
    }

    sequencer.setMixers(&mixer1, &mixer2);

    FastLED.addLeds<WS2812B, DATA_PIN, GRB>(sequencer.leds, NUM_LEDS);
    FastLED.setBrightness(5);

    for (int i = 0; i < NUM_LEDS; i++) {
        for (int j = 0; j < NUM_LEDS; j++) {
            sequencer.leds[j] = CRGB::Black;
        }
        sequencer.leds[i] = CRGB::Red;
        FastLED.show();
        delay(20);
    }
    for (int i = NUM_LEDS - 1; i >= 0; i--) {
        for (int j = 0; j < NUM_LEDS; j++) {
            sequencer.leds[j] = CRGB::Black;
        }
        sequencer.leds[i] = CRGB::Red;
        FastLED.show();
        delay(20);
    }

    // detect diagnostic mode button press (-> debounce needs a few rounds..)
    for (int i = 0; i < 10; i++){
        readButtonStates();
        delay(10);
    }
    
    // diagnostic mode: lights up all LEDs. Pot 1+2 change the color of the LEDS. Pressing any Button will turn off the corresponding LED.
    if (sequencer.trackButtons[5].read()){
        CRGB color = CRGB::White;
        while(true){
            readButtonStates();
            //color.setHSV(analogRead(POTI_PIN_1)>>2,analogRead(POTI_PIN_2)>>2,255);
            uint8_t hue = ((analogRead(POTI_PIN_1)>>3) + (analogRead(POTI_PIN_2)>>3));
            color.setHue(hue);
            for (int i = 0; i < 16; i++) {
                sequencer.leds[i] = sequencer.stepButtons[i].read() ? CRGB::Black : color;
            }
            for (int i = 0; i < 8; i++) {
                sequencer.leds[16+i] = sequencer.functionButtons[i].read() ? CRGB::Black : color;
            }
            for (int i = 0; i < 6; i++) {
                sequencer.leds[24+i] = sequencer.trackButtons[i].read() ? CRGB::Black : color;
                if (sequencer.trackButtons[i].rose()){
                    ParameterSet params = sequencer.audioChannels[i]->getDefaultParams();
                    sequencer.audioChannels[i]->setParam1(params.parameter1);
                    sequencer.audioChannels[i]->setParam2(params.parameter2);
                    sequencer.audioChannels[i]->setParam3(params.parameter3);
                    sequencer.audioChannels[i]->setParam4(params.parameter4);
                    sequencer.audioChannels[i]->setParam5(params.parameter5);
                    sequencer.audioChannels[i]->setParam6(params.parameter6);
                    sequencer.audioChannels[i]->trigger();
                }
            }
            FastLED.show();
        }
    }

    sequencer.input1.init(analogRead(POTI_PIN_1));
    sequencer.input2.init(analogRead(POTI_PIN_2));

    sequencer.leds[0] = CRGB::Black;
    FastLED.show();

    sequencer.persistence.init();

    //while (!SD.begin(BUILTIN_SDCARD)) {
    //  Serial.println(F("Failed to initialize SD library"));
    //  delay(1000);
    //}
}

inline void readButtonState(Bounce &button) {
    button.update();
    // Pulse the Clock (rising edge shifts the next bit).
    digitalWrite(SHIFT_IN_CLOCK_PIN, HIGH);
    // delayMicroseconds(PULSE_WIDTH_USEC);
    digitalWrite(SHIFT_IN_CLOCK_PIN, LOW);
}

/*
 * updates all button states by reading in the values from the shift registers
 */
void readButtonStates() {
    // Trigger a parallel Load to latch the state of the data lines in the input
    // shift register.
    digitalWrite(SHIFT_IN_PLOAD_PIN, LOW);
    delayMicroseconds(PULSE_WIDTH_USEC);
    digitalWrite(SHIFT_IN_PLOAD_PIN, HIGH);

    digitalWrite(SHIFT_IN_CLOCK_PIN, HIGH);
    digitalWrite(SHIFT_IN_CLOCK_PIN, LOW);
    digitalWrite(SHIFT_IN_CLOCK_PIN, HIGH);
    digitalWrite(SHIFT_IN_CLOCK_PIN, LOW);

    readButtonState(sequencer.trackButtons[5]);
    readButtonState(sequencer.trackButtons[4]);
    readButtonState(sequencer.trackButtons[3]);
    readButtonState(sequencer.trackButtons[2]);
    readButtonState(sequencer.trackButtons[1]);
    readButtonState(sequencer.trackButtons[0]);

    readButtonState(sequencer.stepButtons[7]);
    readButtonState(sequencer.stepButtons[6]);
    readButtonState(sequencer.stepButtons[5]);
    readButtonState(sequencer.stepButtons[4]);
    readButtonState(sequencer.stepButtons[3]);
    readButtonState(sequencer.stepButtons[2]);
    readButtonState(sequencer.stepButtons[1]);
    readButtonState(sequencer.stepButtons[0]);

    readButtonState(sequencer.stepButtons[15]);
    readButtonState(sequencer.stepButtons[14]);
    readButtonState(sequencer.stepButtons[13]);
    readButtonState(sequencer.stepButtons[12]);
    readButtonState(sequencer.stepButtons[11]);
    readButtonState(sequencer.stepButtons[10]);
    readButtonState(sequencer.stepButtons[9]);
    readButtonState(sequencer.stepButtons[8]);

    readButtonState(sequencer.functionButtons[7]);
    readButtonState(sequencer.functionButtons[6]);
    readButtonState(sequencer.functionButtons[5]);
    readButtonState(sequencer.functionButtons[4]);
    readButtonState(sequencer.functionButtons[3]);
    readButtonState(sequencer.functionButtons[2]);
    readButtonState(sequencer.functionButtons[1]);
    readButtonState(sequencer.functionButtons[0]);
}

void loop() {
    FastLED.clearData();
    // read all inputs
    #ifdef ENABLE_USBHOST
    usbHost.Task();
    usbHostMIDI.read();
    #endif
    usbMIDI.read();


    readButtonStates();
    cli();
    if (triggerInputFell) {
      sequencer.onTriggerReceived();
      triggerInputFell = false;
    }
    sei();
    // update the sequencer state
    sequencer.updateState();
    // show the current state
    FastLED.show();
}

void onRealTimeSystem(uint8_t rtb) {
    sequencer.onMidiInput(rtb);
}

void onTriggerInputFell(){
    cli();
    triggerInputFell = true;
    sei();
}

void debugAudioUsage() {
    Serial.print("CPU: ");
    Serial.print("all=");
    Serial.print(AudioProcessorUsage());
    Serial.print(",");
    Serial.print(AudioProcessorUsageMax());
    Serial.print("    ");
    Serial.print("Memory: ");
    Serial.print(AudioMemoryUsage());
    Serial.print(",");
    Serial.print(AudioMemoryUsageMax());
    Serial.println();
}

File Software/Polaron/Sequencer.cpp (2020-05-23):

// Copyright (c) 2018 Thomas Zueblin
//
// Author: Thomas Zueblin (thomas.zueblin@gmail.com)
//
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
#include <sstream>
#include "Sequencer.h"

#define MUTE_DIM_FACTOR 20

Sequencer::Sequencer() {
    for (int i = 0; i < NUMBER_OF_FUNCTIONBUTTONS; i++) {
        functionButtons[i] = Bounce();
        functionButtons[i].attach(SHIFT_IN_DATA_PIN);
    }

    for (int i = 0; i < NUMBER_OF_TRACKBUTTONS; i++) {
        trackButtons[i] = Bounce();
        trackButtons[i].attach(SHIFT_IN_DATA_PIN);
    }

    for (int i = 0; i < NUMBER_OF_STEPBUTTONS; i++) {
        stepButtons[i] = Bounce();
        stepButtons[i].attach(SHIFT_IN_DATA_PIN);
    }

    for (int i = 0; i < NUM_LEDS; i++) {
        leds[i] = CRGB::Black;
    }

    for (uint8_t i = 0; i < NUMBER_OF_INSTRUMENTTRACKS; i++) {
        tracks[i].initPatternOpsArmState(i, &patternOpsArmState);
    }
}

/*
* Increments the current step by one on all tracks.
*/
void Sequencer::doStep() {
    for (int i = 0; i < NUMBER_OF_INSTRUMENTTRACKS; i++) {
        SequencerStep &step = tracks[i].doStep();
        if (step.isParameterLockOn()) {
            switch (pLockParamSet) {
                case PLockParamSet::SET1:
                    if (input1.isActive()) {
                        step.params.parameter1 = input1.getValue();
                    }
                    if (input2.isActive()) {
                        step.params.parameter2 = input2.getValue();
                    }
                    break;
                case PLockParamSet::SET2:

                    if (input1.isActive()) {
                        step.params.parameter3 = input1.getValue();
                    }
                    if (input2.isActive()) {
                        step.params.parameter4 = input2.getValue();
                    }
                    break;

                case PLockParamSet::SET3:

                    if (input1.isActive()) {
                        step.params.parameter5 = input1.getValue();
                    }
                    if (input2.isActive()) {
                        step.params.parameter6 = input2.getValue();
                    }
                    break;

                case PLockParamSet::SET3_2:
                    step.triggerMask = triggerPattern;
                    break;
            }
        }
        if (!tracks[i].isMuted() && step.isTriggerOn() && step.isTriggerConditionOn()) {
            ParameterSet & stepParams = step.params;
            audioChannels[i]->setParam1(stepParams.parameter1);
            audioChannels[i]->setParam2(stepParams.parameter2);
            audioChannels[i]->setParam3(stepParams.parameter3);
            audioChannels[i]->setParam4(stepParams.parameter4);
            audioChannels[i]->setParam5(stepParams.parameter5);
            audioChannels[i]->setParam6(stepParams.parameter6);

            audioChannels[i]->trigger();
            #ifdef SEND_MIDI_OUTPUT
                usbMIDI.sendControlChange(12, (uint8_t)(stepParams.parameter1 >> 3), i+1);
                usbMIDI.sendControlChange(13, (uint8_t)(stepParams.parameter2 >> 3), i+1);
                usbMIDI.sendControlChange(14, (uint8_t)(stepParams.parameter3 >> 3), i+1);
                usbMIDI.sendControlChange(15, (uint8_t)(stepParams.parameter4 >> 3), i+1);
                //Serial.println((uint8_t)(stepParams.parameter5 >> 3));
                usbMIDI.sendControlChange(16, (uint8_t)(stepParams.parameter5 >> 3), i+1);
                usbMIDI.sendControlChange(17, (uint8_t)(stepParams.parameter6 >> 3), i+1);
                usbMIDI.sendNoteOn(60+i, 100, i+1);
                triggers[i]=1;
            #endif
        } 
        #ifdef SEND_MIDI_OUTPUT
            else {
                if (triggers[i] > 0){
                    triggers[i]--;
                    if (triggers[i] == 0){
                        usbMIDI.sendNoteOff(60+i, 0, i+1);    
                    }
                }
            }
        #endif
        
        
    }
}

void Sequencer::start() {
    if (!running) {
        running = true;
        clock.onStart();
    }
}

void Sequencer::stop() {
    if (running) {
        running = false;
        for (int i = 0; i < NUMBER_OF_INSTRUMENTTRACKS; i++) {
            tracks[i].onStop();
        }
        clock.onStop();
    }
}

void Sequencer::doStartStop() {
    if (running){
        stop();
    } else {
        start();
    }
}

void Sequencer::updateState() {

    input1.update((uint16_t)analogRead(POTI_PIN_1));
    input2.update((uint16_t)analogRead(POTI_PIN_2)); 

    #ifdef SEND_MIDI_OUTPUT
        if (!running){
            int offset = pLockParamSet == PLockParamSet::SET1 ? 0 : pLockParamSet == PLockParamSet::SET2 ? 2 : 4;
            if (input1.isActive()){
                usbMIDI.sendControlChange(12 + offset, input1.getValue() >> 3, selectedTrack+1, 0);
            }
            if (input2.isActive()){
                usbMIDI.sendControlChange(13 + offset, input1.getValue() >> 3, selectedTrack+1, 0);
            }
        }
    #endif


    hasActivePLockReceivers = false;
    for (int i = 0; i < NUMBER_OF_INSTRUMENTTRACKS; i++) {
        if (tracks[i].getCurrentPattern().isInPLockMode()) {
            hasActivePLockReceivers = true;
            break;
        }
    }

    if (functionButtons[BUTTON_SET_PARAMSET_1].rose()) {
        pLockParamSet = PLockParamSet::SET1;
        deactivateSensors();
    } else if (functionButtons[BUTTON_SET_PARAMSET_2].rose()) {
        pLockParamSet = PLockParamSet::SET2;
        deactivateSensors();
    } else if (functionButtons[BUTTON_SET_PARAMSET_3].rose()) {
        if (pLockParamSet == PLockParamSet::SET3 && hasActivePLockReceivers){
            pLockParamSet = PLockParamSet::SET3_2;
            triggerPattern = 0b00111111;
        } else {
            pLockParamSet = PLockParamSet::SET3;
        }
        deactivateSensors();
    } 
    
    functionMode = calculateFunctionMode();
    if (functionMode != previousFunctionMode) {
        deactivateSensors();
        shiftPressedModeChange = functionMode != FunctionMode::PATTERN_OPS && functionButtons[BUTTON_SET_PATTERN].read();
    }
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

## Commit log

2018-09-28 updated codebase to last prototype version
2018-09-28 removed currently unused files
2018-10-04 added possibility to switch between 3 different parameter sets
2018-11-01 combined software and hardware into one polaron repo.
    [sequencer-B.Cu.gbl, sequencer-B.Mask.gbs, sequencer-B.SilkS.gbo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]
2018-11-01 added a way to configure default settings for each instrument track
2018-11-08 added a Sensor class that wraps the potentiometer input an adds some logic
2018-11-10 - added possibility to switch (and copy-paste) all track patterns at once or each track individually - added a new audiochannel exploring two ringmodulated sinus oscilators
2018-11-15 - changed env to an analog style env that will start the attack at the current env value and not necessarily at zero - fixed some behaviour regarding the timing/clock changes - added a proper kickdru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
    [Polaron.ino, Sequencer.cpp, effect_shaped_envelope.cpp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]
2018-11-24 PCB rev 1.2
    [sequencer.kicad_pcb, sequencer.sch]
2018-12-13 added assembly images
2019-01-17 feature added to control panorama / volume of each instrument channel by pressing down the track select button and turing pot1 for volume / pot2 for channel panning
2019-01-17 added links to wiki and a note about the ground loop problem
2019-03-03 rev 1.2 pcb images
2019-03-07 changed simple-delay to accept number of samples as input instead of milliseconds.
2019-03-07 param_set change buttons are now always slightly illuminated in order for better visibility for this group of buttons
2019-03-14 using a short click sample to fatten up the kick. Adding an example on how one might use pitchable in-memory samples in audio-channels
    [HatsChannel.h]
2019-03-28 - fixed some issues with sequencer stepping / triggering sounds - major cleanup / some refactorings - minor changes in the sound engine
    [Polaron.ino, Sequencer.cpp]
2019-03-28 fixed a problem with midi-sync (polaron would run 1 clock cycle ahead)
    [Polaron.ino, Sequencer.cpp, Sequencer.h]
2019-03-28 rotated pot 1 / 2 footprint by 180 degrees
    [sequencer.kicad_pcb]
2019-03-30 rev 1.3 pcb - Pots rotated by 180 degrees - Added circuit for trigger input
    [sequencer-B.Cu.gbl, sequencer-B.Mask.gbs, sequencer-B.SilkS.gbo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]
2019-03-31 rearranged some of the audio objects to refect the signal flow, as this apparently has an effect on the latency of the instrument
2019-04-04 added LED ordering image
2019-04-04 added led-order svg
2019-04-04 - Start/Stop LED now blinks in tempo, when the sequencer is stopped - Slightly tuned the activate/deactivate behaviour of the Potentiometers, as they would sometimes activate themselves (noise in the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
    [Sequencer.cpp, Sequencer.h]
2019-04-06 changed ordering of parameters in boomchannel to better group according to functions fixed a problem where the volume could change unintended on channels that have parameter lock recording on
    [Sequencer.cpp]
2019-04-07 when input1 or 2 is active, this is now indicated by a red parameter lock LED instead of blinking / non-blinkin
2019-04-19 feat: added dignostic mode that allows to check if a build is correctly working (LEDs, buttons, pots, audio output). dignostic mode can be entered by pressing and holding track button 5 (button close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
    [Polaron.ino]
2019-04-25 feat: tempo is now changed by pressing and holding SET_PATTERN_LENGTH and SWITCH_PATTERN buttons at the same time. When in this mode, the track buttons allow to change the tempo in small increments (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
2019-06-13 Moved most timing logic into a new clock class. Swing now also supported when clocking the polaron to midi-clock. Trigger input now uses an interrupt to detect pulses, so that none of them should be 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
    [Clock.cpp, Clock.h, Polaron.ino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]
2019-06-16 [FIX] fixed a problem where copy pasting a pattern did not copy the full state of the source pattern onto the destination pattern [INTERNAL] stopped using a static int for state handling in tracks
    [Sequencer.cpp, Sequencer.h]
2019-06-20 Hardware Rev 1.4: Function buttons and track buttons now use SMD Resistors, so that there is space on the PCB for text labels for each function button
    [sequencer-B.Cu.gbl, sequencer-B.Mask.gbs, sequencer-B.SilkS.gbo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]
2019-07-25 changed the way the shift button presses work: its now enough to press shift when entering a mode, after that the shift button can be released and the mode is still in shift mode
2019-07-25 added changes for rev 1.3 and 1.4 PCB
2019-09-05 - tempo and swing is now also stored when a project is saved - reverted the p-lock undo pattern function, as it doesnt belong in this branch (might pick it up again later)
    [Clock.h, ProjectPersistence.cpp, Sequencer.cpp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]
2020-04-11 allow usbhost feature to be switched on/off during compilation
2020-05-15 BroadBandNoiseChannel replaced with BapChannel
    [Polaron.ino]

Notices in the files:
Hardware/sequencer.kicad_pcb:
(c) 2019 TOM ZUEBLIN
